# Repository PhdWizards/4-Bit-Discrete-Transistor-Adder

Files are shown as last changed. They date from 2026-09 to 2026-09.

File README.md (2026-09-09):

# 4-Bit Transistor Adder
A fully functional **4-bit binary adder** built using discrete transistor-resistor logic and standard 74HC-series logic ICs.
The project was developed from the initial logic design and transistor-level simulation to a custom two-layer PCB, PCB manufacturing, component assembly, and hardware testing.
The final circuit accepts two 4-bit binary numbers, adds them together, converts the resulting 5-bit value into decimal digits, and displays the result on two 7-segment displays.

## Overview
The main goal of this project was to design and build a physical digital calculator without relying on a microcontroller for the main arithmetic logic.
The core 4-bit adder was developed using **discrete transistor-resistor logic**.
The project includes:
- 4-bit binary addition
- Discrete transistor-based logic
- 5-bit binary result
- Binary-to-BCD conversion
- Two 7-segment displays
- CD4511 BCD-to-7-segment drivers
- Manual binary input using switches
- LED indicators for the binary result
- Custom two-layer PCB
- Complete KiCad schematic
- PCB design and Gerber manufacturing files
- Interactive Bill of Materials
- Falstad and Tinkercad simulations

## Specifications
| Parameter | Value |
|---|---|
| Operation | 4-bit + 4-bit binary addition |
| Input A | 4 bits |
| Input B | 4 bits |
| Result | 5 bits |
| Result range | 0–30 |
| Supply voltage | 5 V |
| Power input | USB-C |
| PCB | 2-layer |
| PCB size | 166.37 × 181.61 mm |
| Main transistor | BC337-25 |
| Transistors | 100 |
| Resistors | 178 |
| 7-segment displays | 2 |
| BCD drivers | 2 × CD4511 |
| Binary input switches | 8 |
| LEDs | 6 |
| Microcontroller | None |

## How It Works

Two 4-bit binary values are entered using eight switches:
```text
A3 A2 A1 A0
B3 B2 B1 B0
```
The values are added together by the transistor-based logic, producing a 5-bit result:
```text
S4 S3 S2 S1 S0
```
The maximum possible result is:
```text
1111₂ + 1111₂ = 11110₂
```
which corresponds to:
```text
30₁₀
```
The 5-bit result is then converted into BCD:
```text
        5-bit Binary Result
                  │
                  ▼
          Binary-to-BCD
           Conversion
                  │
          ┌───────┴───────┐
          ▼               ▼
      Tens BCD         Ones BCD
          │               │
          ▼               ▼
       CD4511           CD4511
          │               │
          ▼               ▼
      7-Segment        7-Segment
       Display           Display
```
For example:
```text
10101₂ = 21₁₀
```
The two displays therefore show:
```text
21
```

## Hardware

### Final Board
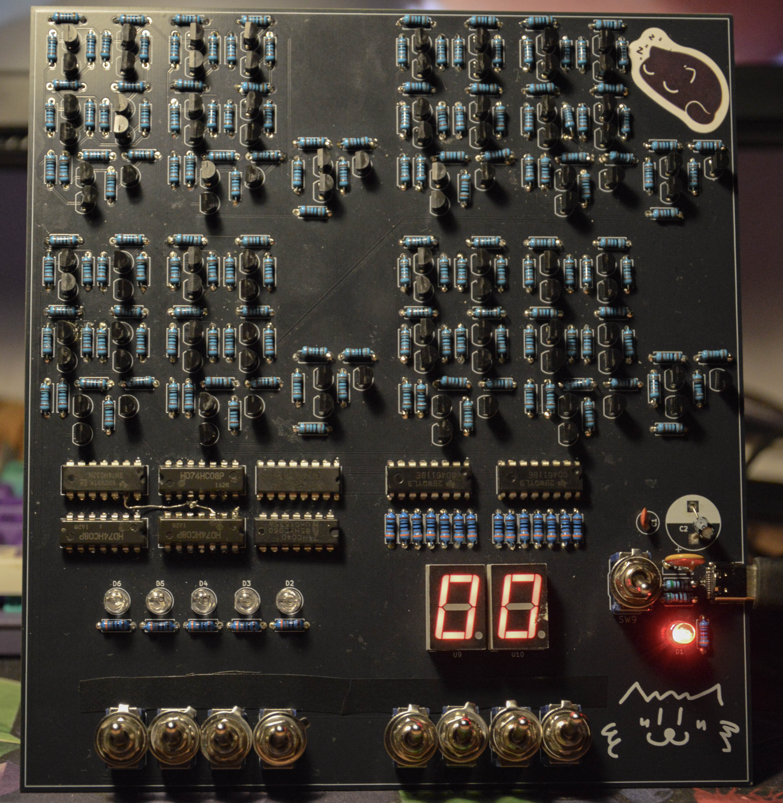
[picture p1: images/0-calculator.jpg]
Final Calculator

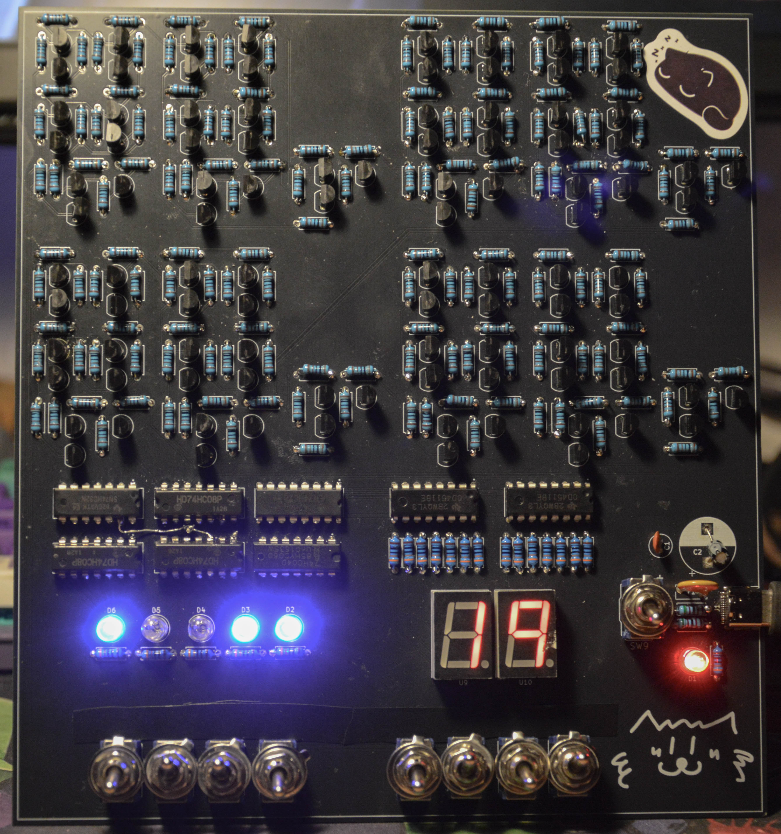
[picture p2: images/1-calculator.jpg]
Working Calculator


## PCB Design

The PCB was designed in **KiCad** as a two-layer board.

### Front Side
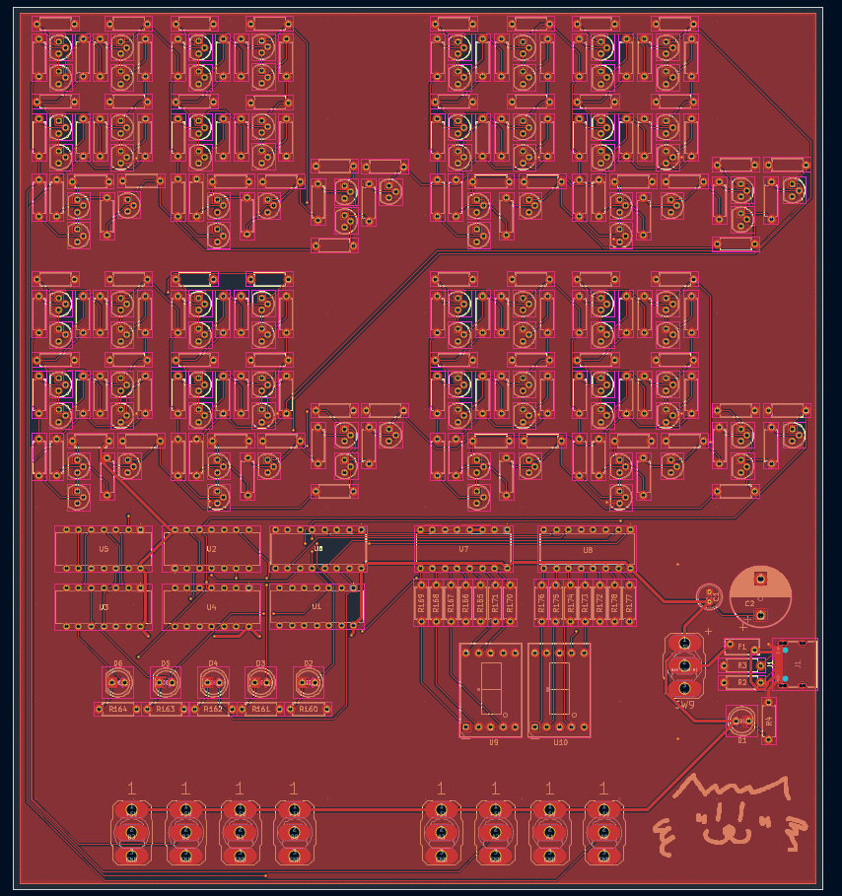
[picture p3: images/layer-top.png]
PCB Front


### Back Side
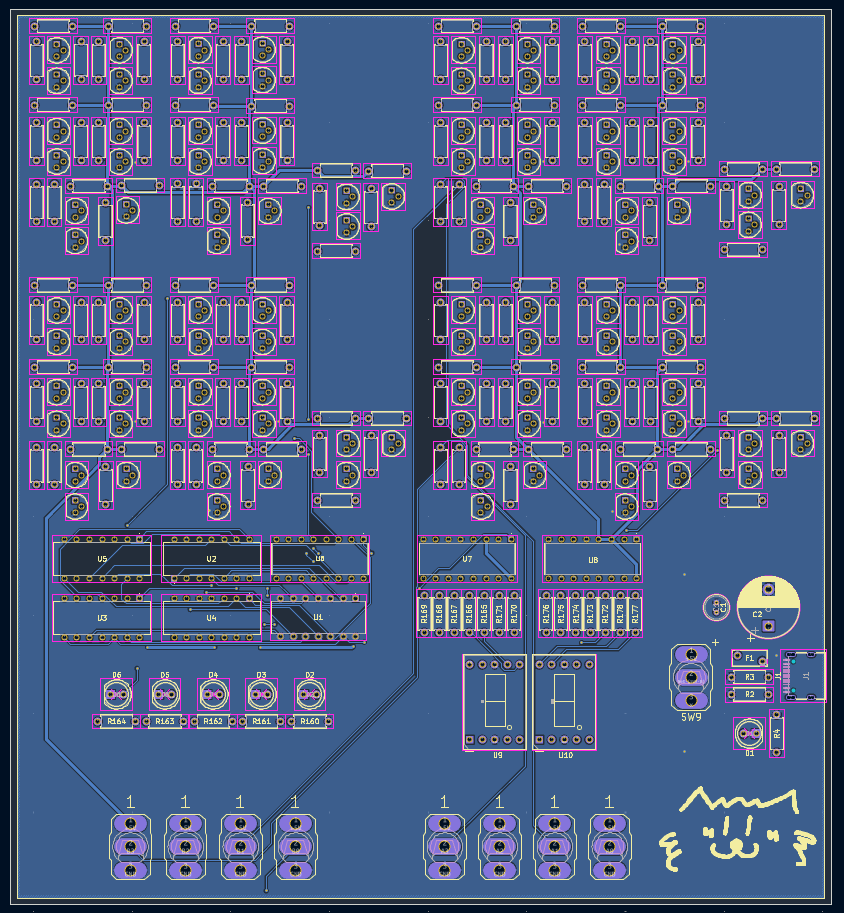
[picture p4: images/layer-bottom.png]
PCB Back


### All Copper Layers
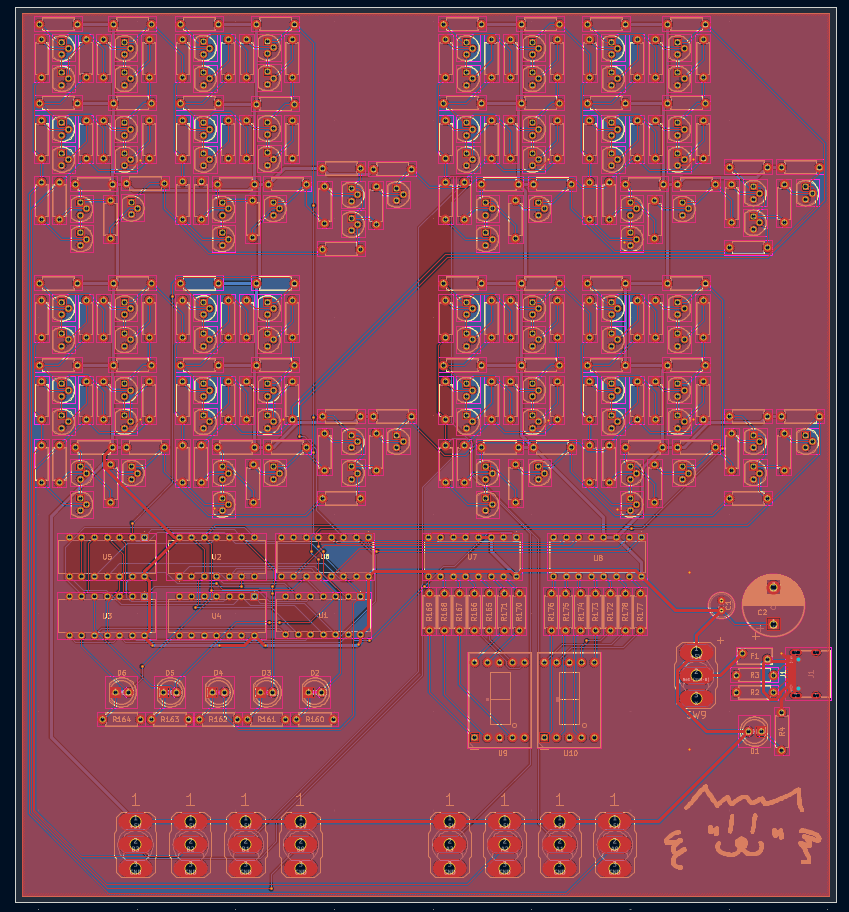
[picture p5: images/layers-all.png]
PCB All Layers


### 3D Model
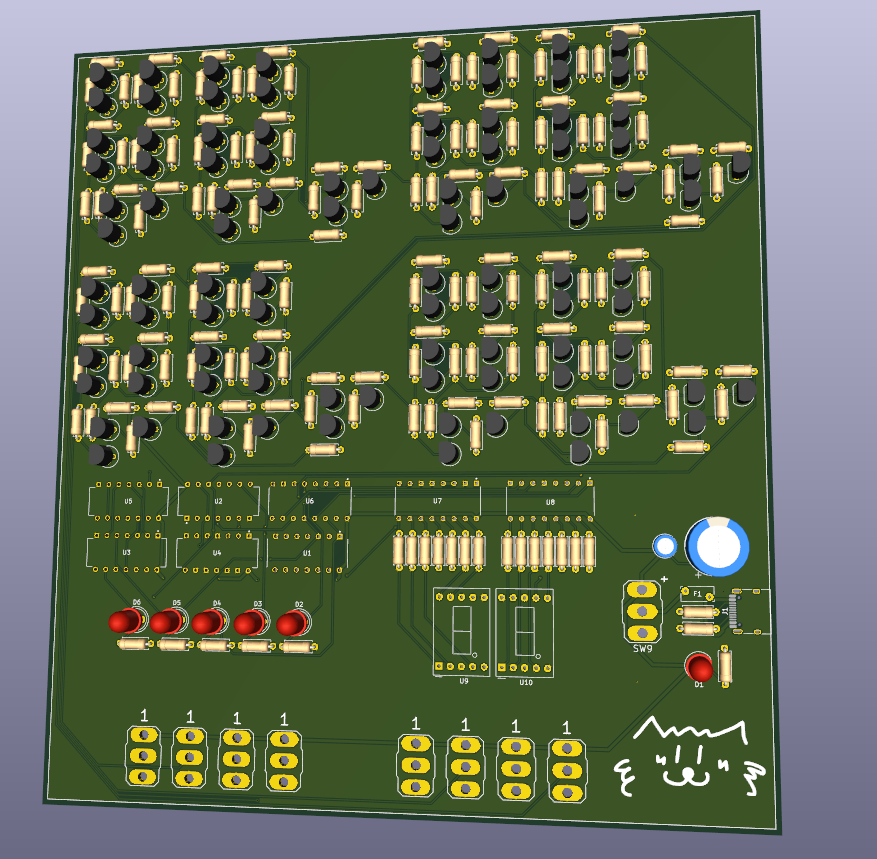
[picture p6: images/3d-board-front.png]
PCB 3D Front

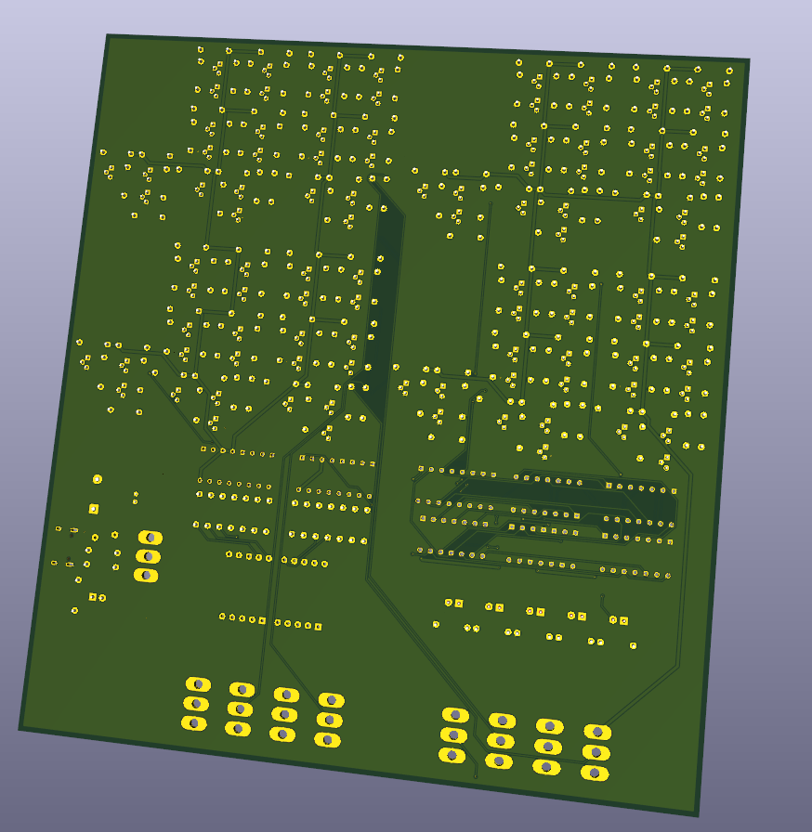
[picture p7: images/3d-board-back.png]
PCB 3D Back


## Schematic
The complete schematic was designed in KiCad and contains the transistor-based adder, logic ICs, BCD conversion, display drivers, inputs, indicators, and power circuitry.
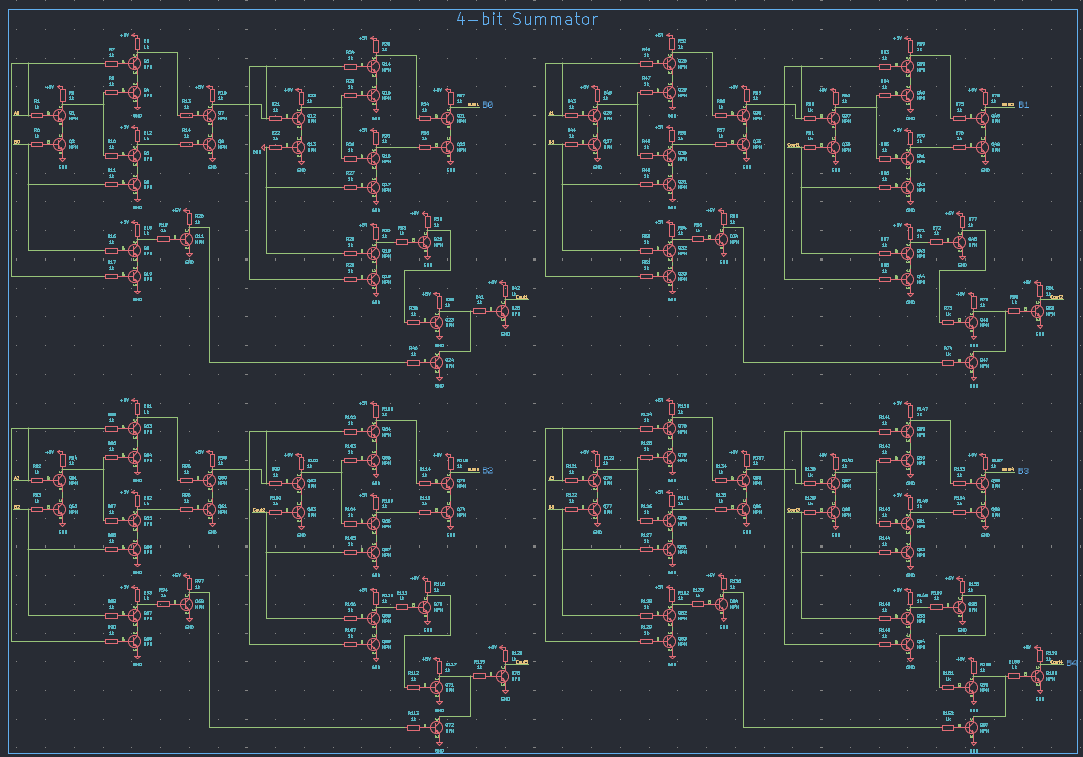
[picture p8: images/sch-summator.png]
Sum-Schematic

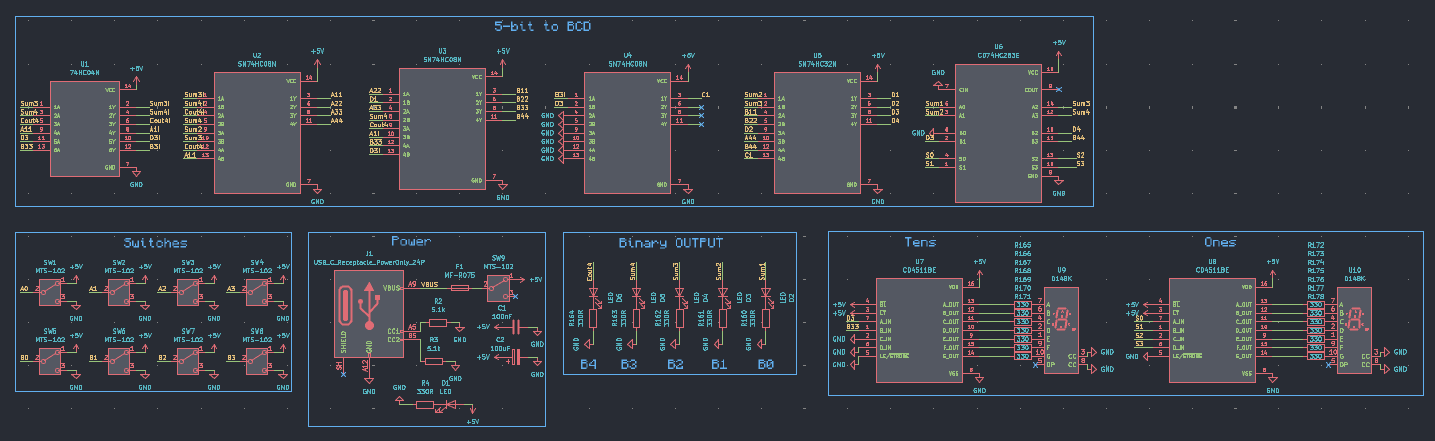
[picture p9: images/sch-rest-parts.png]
Rest-Schematic

A PDF version of the schematic is included in the `schematic` directory.
[**Open Schematic PDF**](schematic/sch.pdf)

## Bill of Materials

An **Interactive BOM** generated from KiCad is included in the repository.
It provides:
- Component references
- Component values
- Footprints
- Quantities
- Front and back PCB views
- Component locations
[**Open Interactive BOM**](bom/calculator-BOM.html)

## Simulation

Simulation was an important part of the development process.
Two different simulation environments were used for different stages of the project.

### Falstad
Falstad was used to learn and develop the transistor-based logic from the ground up.
The 4-bit adder was built step by step, starting from transistor-level digital logic and gradually combining the individual stages into a complete working 4-bit adder.
A downloadable Falstad simulation file is also included in the repository.
[**Open Simulation Documentation**](simulation/README.md)

### Tinkercad
Tinkercad was used to verify the digital logic and binary-to-BCD conversion.
The interactive Tinkercad simulation can be accessed through the simulation documentation.

## Development Process

The project was developed through the following stages:
```text
Concept
   ↓
Logic Design
   ↓
Transistor-Level Development
   ↓
Falstad Simulation
   ↓
Working 4-Bit Adder
   ↓
Tinkercad Simulation
   ↓
KiCad Schematic
   ↓
PCB Layout
   ↓
PCB Manufacturing
   ↓
Component Assembly
   ↓
Hardware Testing
```
The purpose of this workflow was to validate the logic progressively before moving to the final physical implementation.

## Manufacturing Files

The repository contains the files required to reproduce the PCB.
The `pcb` directory includes:
- KiCad PCB files
- Gerber manufacturing files
The schematic directory contains the KiCad schematic and PDF documentation.

## Repository Structure
```text
4-Bit-Transistor-Adder/
│
├── 📁 bom/
│   └── Interactive BOM
│
├── 📁 images/
│   ├── Project photos
│   ├── PCB renders
│   ├── PCB layers
│   ├── Schematic images
│   └── Simulation screenshots
│
├── 📁 pcb/
│   ├── KiCad PCB files
│   └── Gerber files
│
├── 📁 schematic/
│   ├── KiCad schematic
│   └── Schematic PDF
│
├── 📁 simulation/
│   ├── README.md
│   └── Falstad simulation file
│
└── README.md
```

# Tools Used
- **KiCad** — schematic and PCB design
- **Falstad Circuit Simulator** — transistor-level logic development
- **Tinkercad Circuits** — digital logic simulation

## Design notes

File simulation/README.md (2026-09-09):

# Simulation
This folder contains the circuit simulations used during the development of the project.
The simulations were created to study, verify, and test the digital logic before moving to the final schematic and PCB implementation.
Two simulation environments were used during the development process:
- **Falstad Circuit Simulator** — used to learn and develop the transistor-based 4-bit adder from the ground up.
- **Tinkercad Circuits** — used to verify the binary-to-BCD conversion and the final digital logic.

## Overview
The final circuit takes a **5-bit binary input** and converts it into a decimal value displayed on two 7-segment displays.
The binary input is provided using DIP switches. The logic circuit processes the input and produces the corresponding BCD representation for the:
- **Tens digit**
- **Ones digit**
Two **CD4511** BCD-to-7-segment decoder/drivers are used to control the displays.

## Circuit
The simulation contains the following main functional blocks:
```text
          5-bit Binary Input
                 │
                 ▼
        ┌──────────────────┐
        │ Digital Logic    │
        │                  │
        │ 74HC04           │
        │ 74HC08           │
        │ 74HC32           │
        │ 74HC283          │
        └────────┬─────────┘
                 │
                 ▼
          BCD Conversion
                 │
          ┌──────┴──────┐
          ▼             ▼
       Tens BCD      Ones BCD
          │             │
          ▼             ▼
      CD4511          CD4511
          │             │
          ▼             ▼
     7-Segment       7-Segment
      Display         Display
```

## Components Used

### Logic ICs
| Component | Function |
|---|---|
| 74HC04 | NOT gates |
| 74HC08 | AND gates |
| 74HC32 | OR gates |
| 74HC283 | 4-bit binary adder |
| CD4511 | BCD-to-7-segment decoder/driver |

### Other Components
- 2 × 7-segment displays
- DIP switches for binary input
- Current-limiting resistors
- 5 V power supply

# Falstad Simulation
Falstad was the first simulation environment used during the development of the project.
Instead of starting with a complete circuit, the 4-bit adder was developed **from the ground up** using discrete transistor-resistor logic.
The main purpose of this stage was to understand how digital logic gates can be constructed from individual transistors and how these gates can be combined to perform binary addition.

## Learning and Development Process
The development in Falstad followed several stages:
```text
Transistor Basics
       ↓
Logic Gates
       ↓
Half Adder
       ↓
Full Adder
       ↓
4-Bit Adder
```
The circuit was built step by step while testing the behavior of each stage.
The final result was a **fully working 4-bit binary adder** implemented using discrete transistor logic.

## 4-Bit Adder
The completed Falstad simulation contains four 1-bit addition stages connected together to form a 4-bit binary adder.
Each stage processes:
```text
A
B
Cin
```
and produces:
```text
Sum
Cout
```
The carry output of each stage is passed to the next bit.
```text
        ┌─────────────┐
A0 ────►│             │
B0 ────►│  1-Bit      │───► S0
Cin ───►│  Adder      │
        └──────┬──────┘
               │ Cout
               ▼
        ┌─────────────┐
A1 ────►│             │
B1 ────►│  1-Bit      │───► S1
C1 ────►│  Adder      │
        └──────┬──────┘
               │ Cout
               ▼
              ...
```
The completed 4-bit adder was then used as the basis for the hardware implementation.

## Falstad Simulation
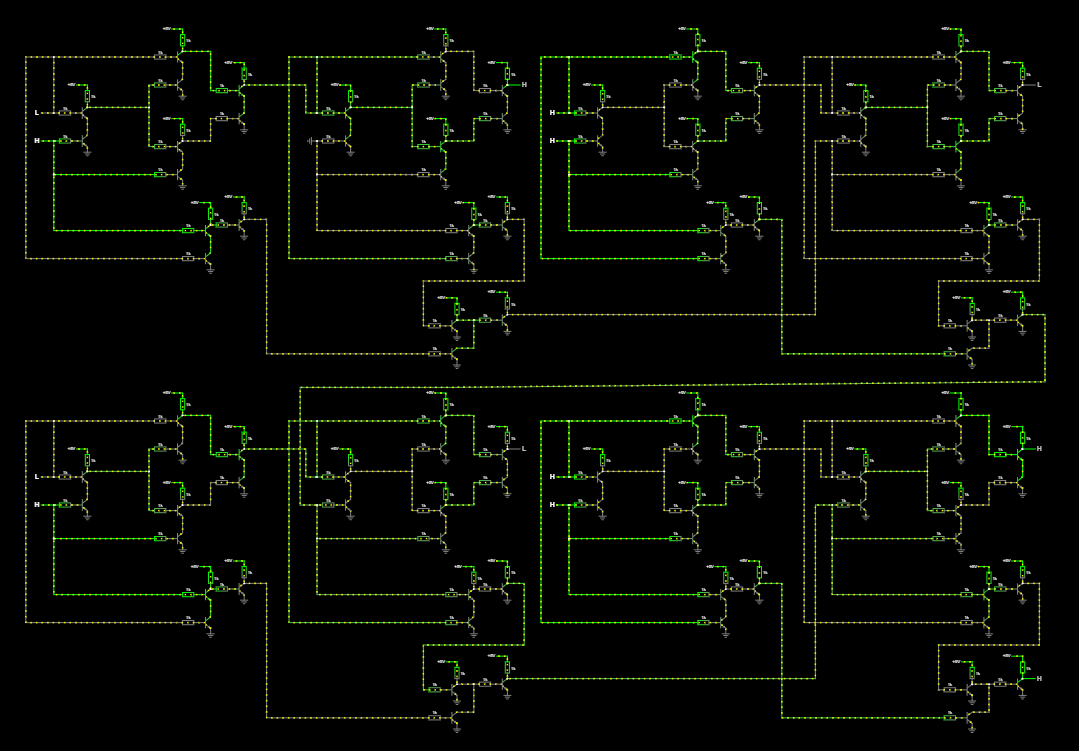
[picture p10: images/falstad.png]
Falstad 4-Bit Adder


### Simulation File
[**Download the Falstad Simulation File**](Summator4bit.txt)
After downloading the file, open it in Falstad to view the complete circuit and inspect how the transistor-based logic works.

# Tinkercad Simulation
The Tinkercad simulation was created to verify the digital logic and the binary-to-BCD conversion before moving to the final schematic and PCB implementation.
The simulation uses standard logic ICs to process the binary input and generate the corresponding BCD output.

## Input
The input is selected using five DIP switches:
```text
B4 B3 B2 B1 B0
```
Each switch represents one bit of the binary input.
The 5-bit input can represent values from:
```text
00000₂ = 0₁₀
```
to:
```text
11111₂ = 31₁₀
```
For example:
```text
Input: 10101₂
```
represents:
```text
21₁₀
```

## Output
The resulting binary value is converted into BCD and split into two decimal digits:
```text
          5-bit Binary
                │
                ▼
        ┌───────────────┐
        │ BCD Conversion│
        └───────┬───────┘
                │
       ┌────────┴────────┐
       ▼                 ▼
   Tens BCD           Ones BCD
       │                 │
       ▼                 ▼
    CD4511             CD4511
       │                 │
       ▼                 ▼
  7-Segment          7-Segment
    Display            Display
```
For example:
```text
Binary: 10101₂

Decimal: 21₁₀

Tens BCD:
0010

Ones BCD:
0001
```
The two 7-segment displays therefore show:
```text
21
```

## Simulation Screenshot
The following image shows the complete simulated circuit in Tinkercad:
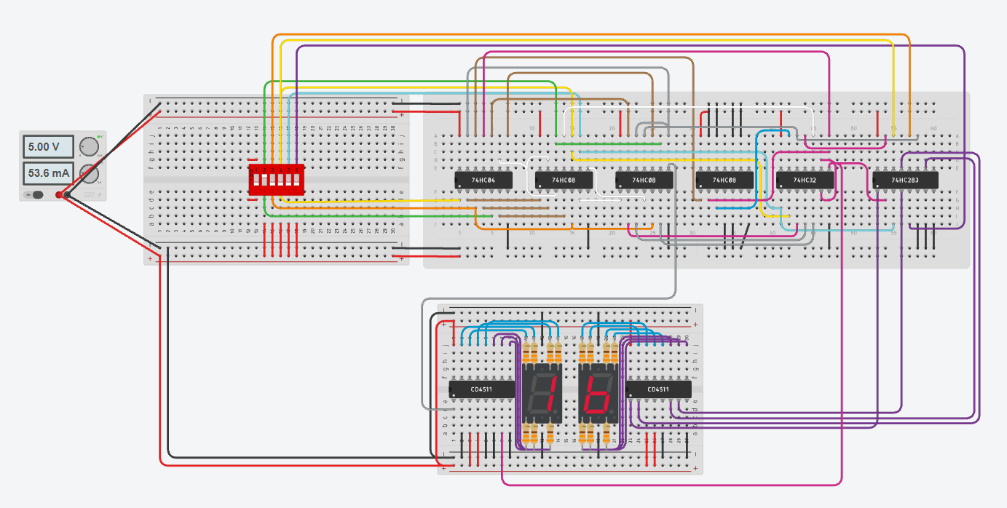
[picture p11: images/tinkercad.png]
Tinkercad Simulation


## Interactive Simulation
The complete interactive simulation is available on Tinkercad:
[**Open Tinkercad Simulation**](https://www.tinkercad.com/things/4N6F5v3ThxK-5-bit-to-bcd-double-dabble)
The simulation can be used to change the binary input and observe the corresponding decimal output on the two 7-segment displays.

# Verification
The simulations were used to verify different parts of the project before moving to the physical implementation.

### Falstad
The Falstad simulation was used to:
- Learn transistor-based digital logic
- Build and test logic gates
- Develop a 1-bit adder
- Combine multiple stages into a 4-bit adder
- Verify carry propagation
- Develop the core transistor-based adder logic

### Tinkercad
The Tinkercad simulation was used to:
- Verify the 5-bit binary input
- Test the digital logic
- Verify binary-to-BCD conversion
- Test the tens digit generation
- Test the ones digit generation
- Verify CD4511 decoder operation
- Verify the 7-segment display output
Different input combinations were tested to ensure that the displayed decimal value matched the expected result.

# Development Process
The simulations were part of the overall hardware development process:
```text
Logic Design
     ↓
Falstad
     ↓
Transistor-Based 4-Bit Adder
     ↓
Tinkercad
     ↓
Binary-to-BCD Logic
     ↓
KiCad Schematic
     ↓
PCB Design
     ↓
PCB Manufacturing
     ↓
Component Assembly
     ↓
Hardware Testing
```
The simulation stage made it possible to develop and verify the logic before committing to the final PCB implementation.

# Related Project Files
The project repository contains the complete design files, including:
```text
📁 bom/
📁 images/
📁 pcb/
📁 schematic/
📁 simulation/
```
The `images` folder contains screenshots and photographs from the development process.
The `simulation` folder contains this documentation.
---

[**Back to Main README**](../README.md)

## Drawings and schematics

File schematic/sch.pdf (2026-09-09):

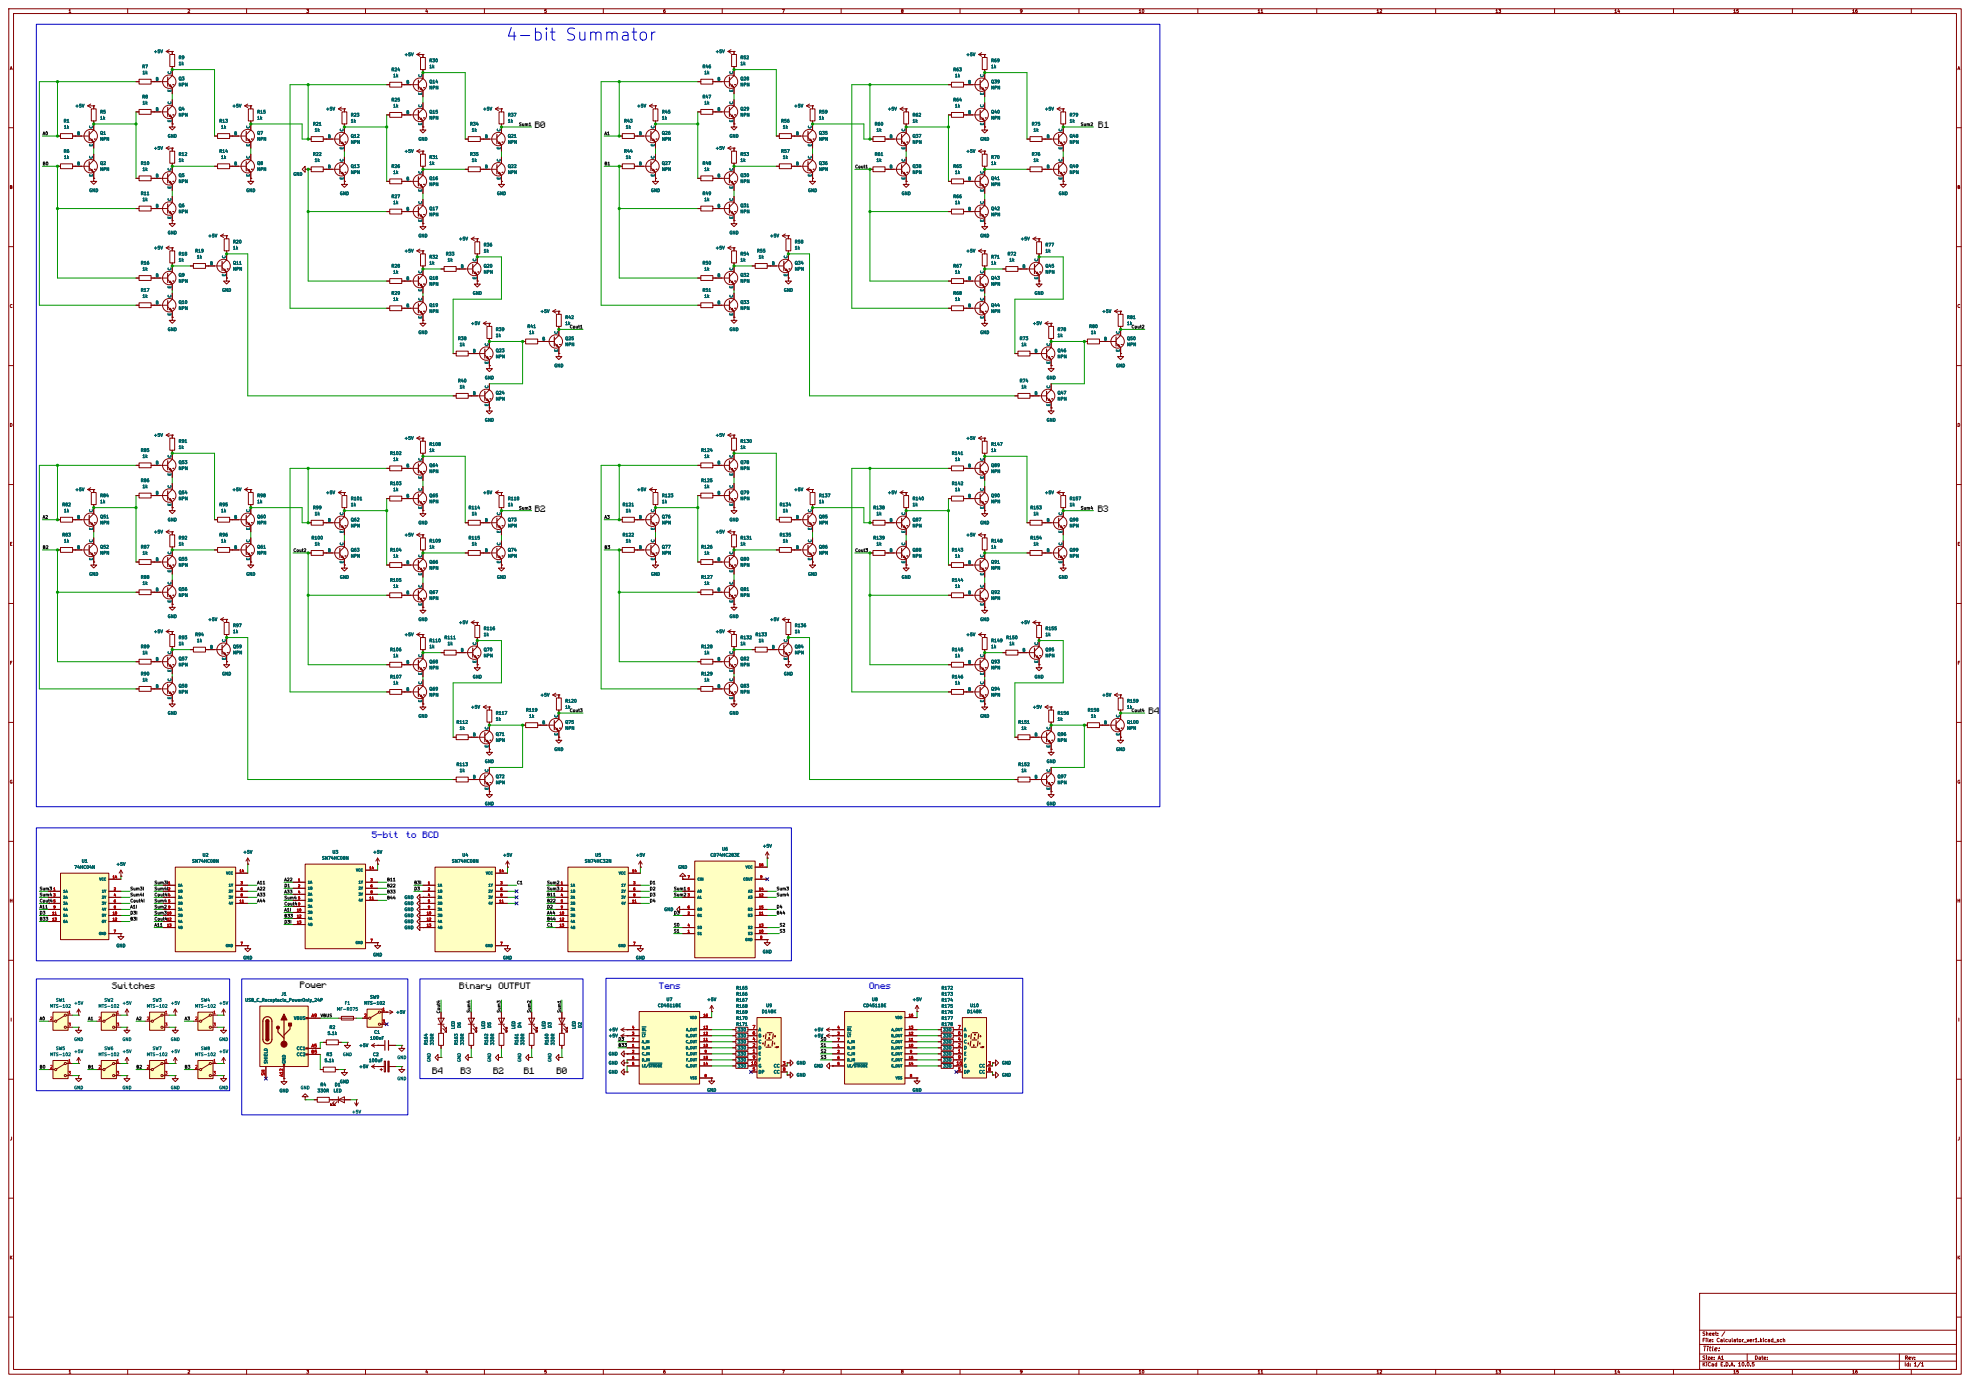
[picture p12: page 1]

Size: A1 | Rev:
KiCad E.D.A. 10.0.5 | Id: 1/1

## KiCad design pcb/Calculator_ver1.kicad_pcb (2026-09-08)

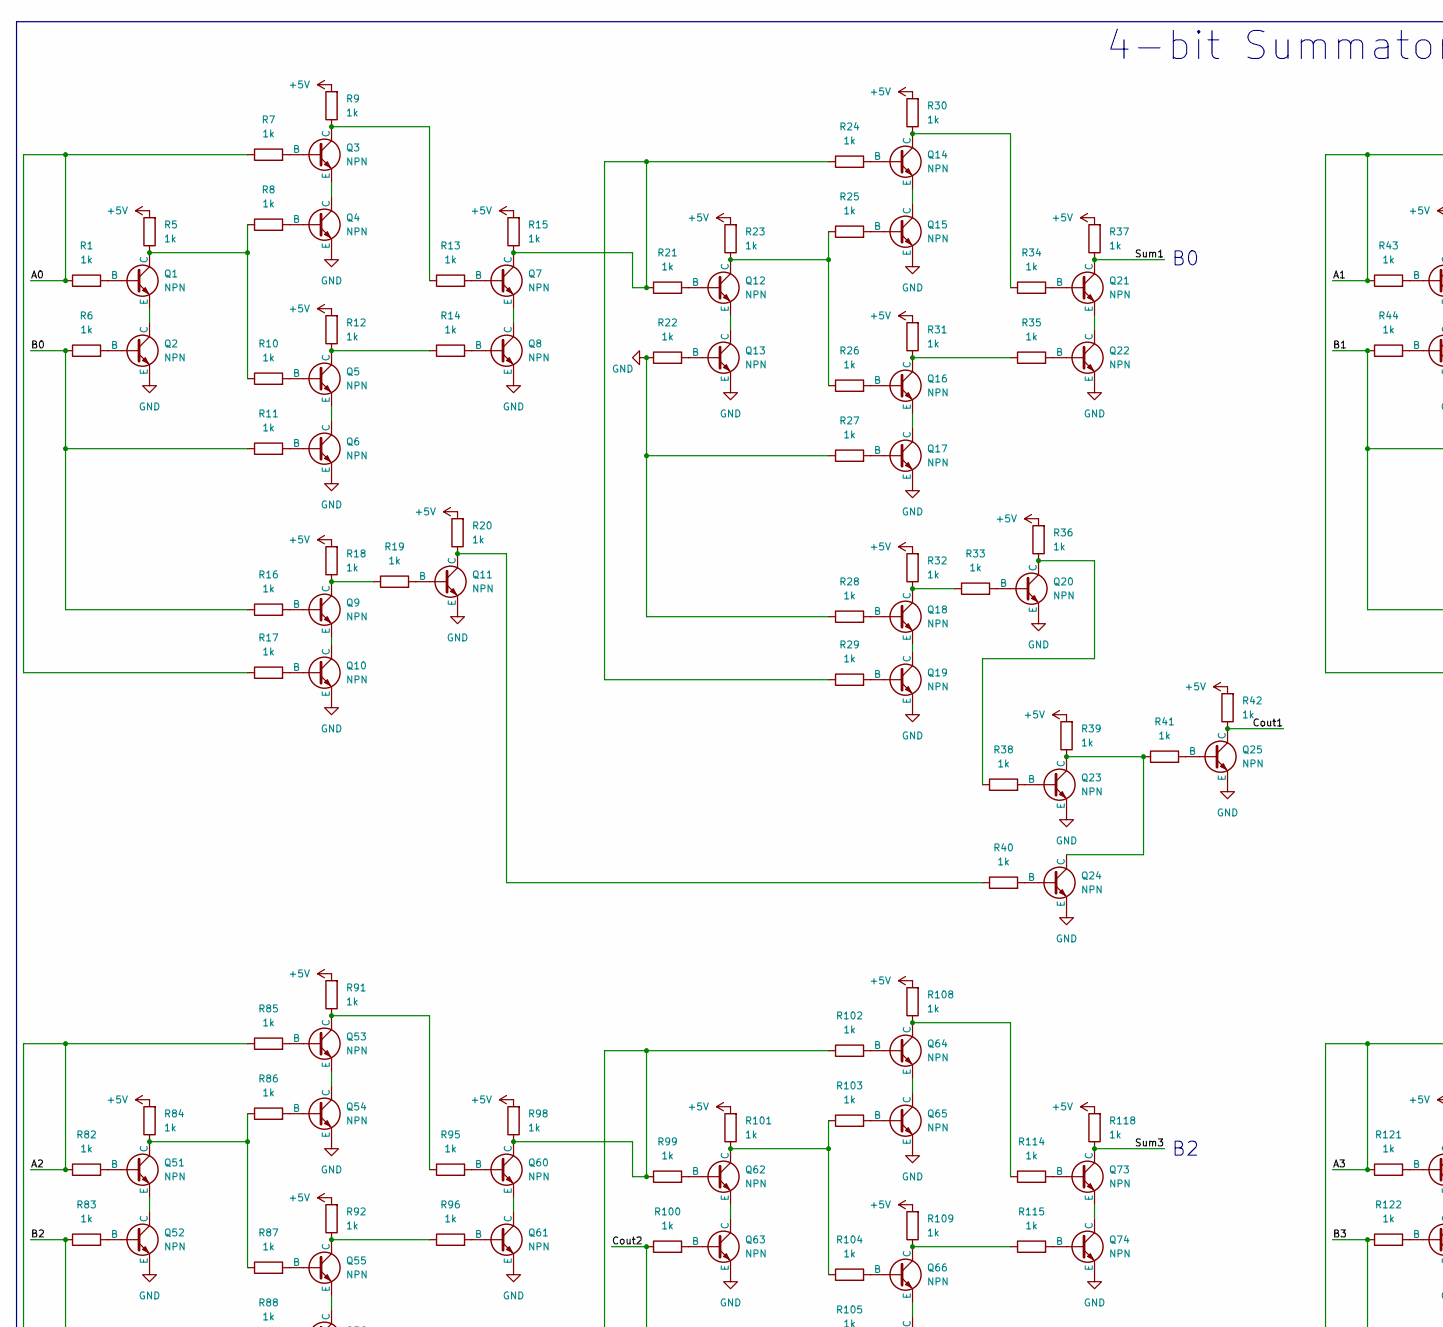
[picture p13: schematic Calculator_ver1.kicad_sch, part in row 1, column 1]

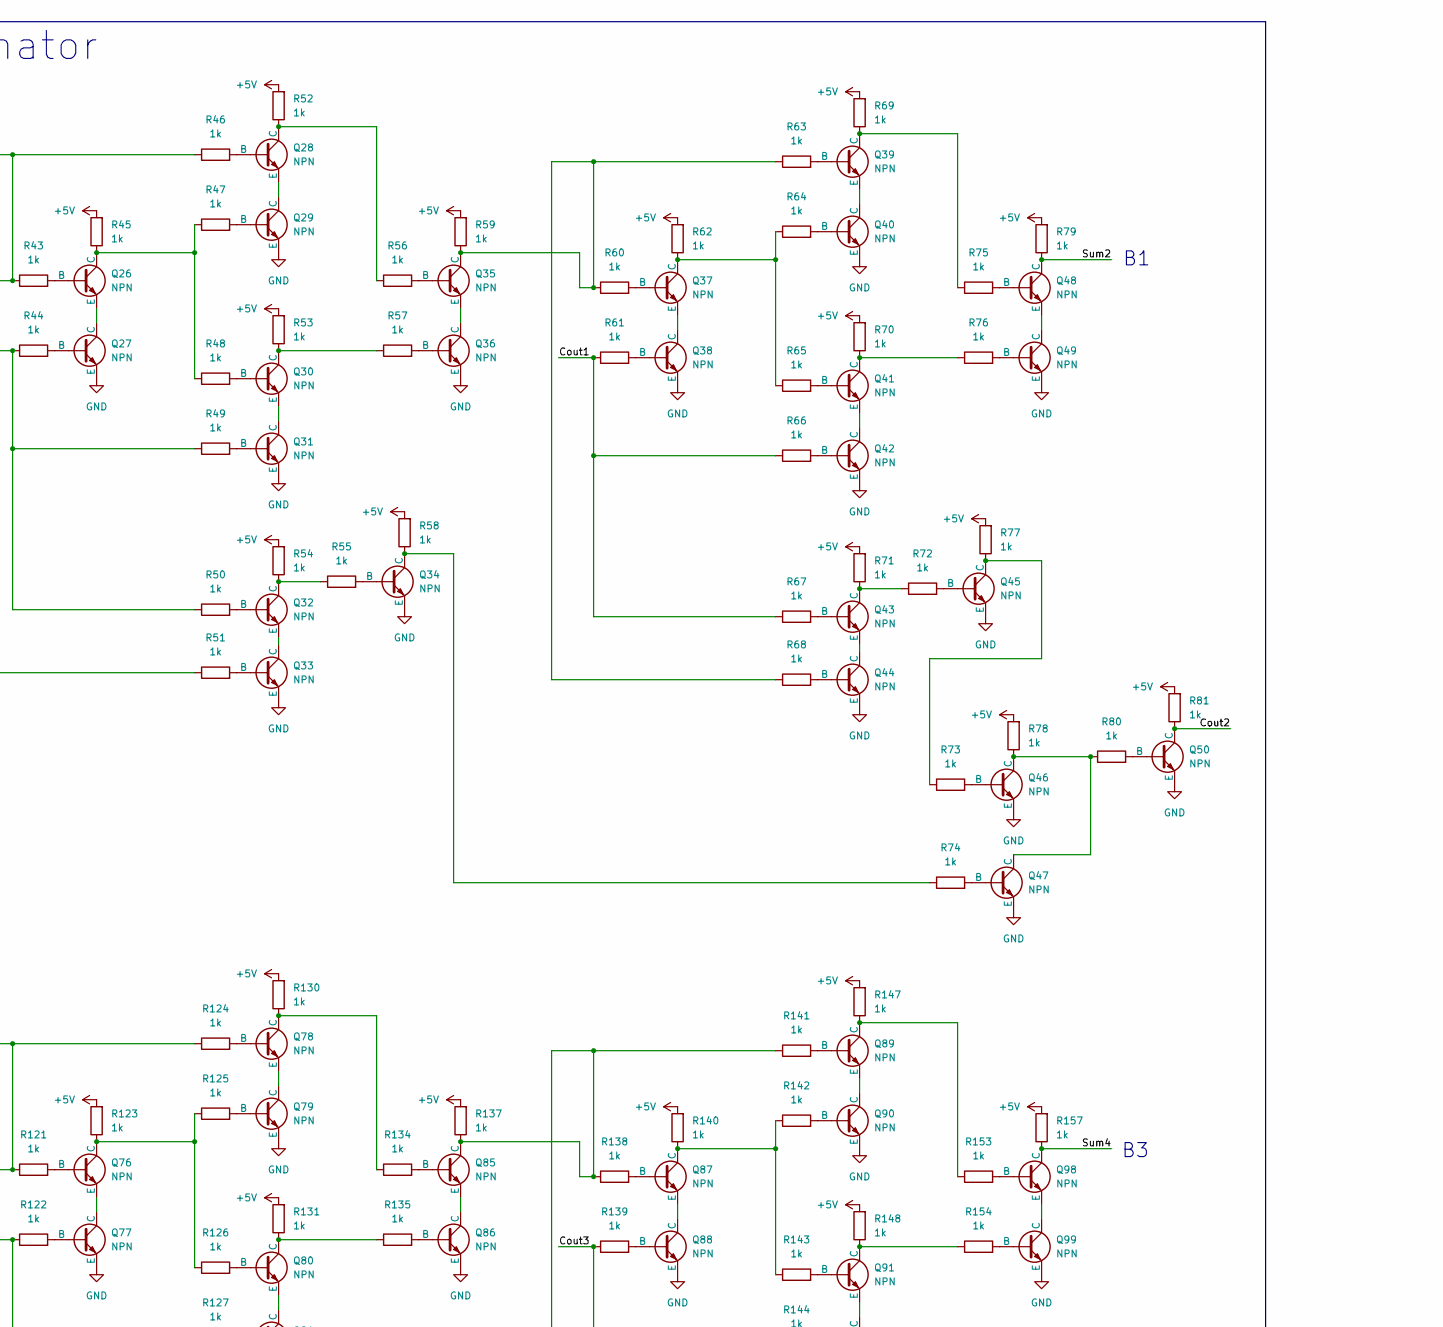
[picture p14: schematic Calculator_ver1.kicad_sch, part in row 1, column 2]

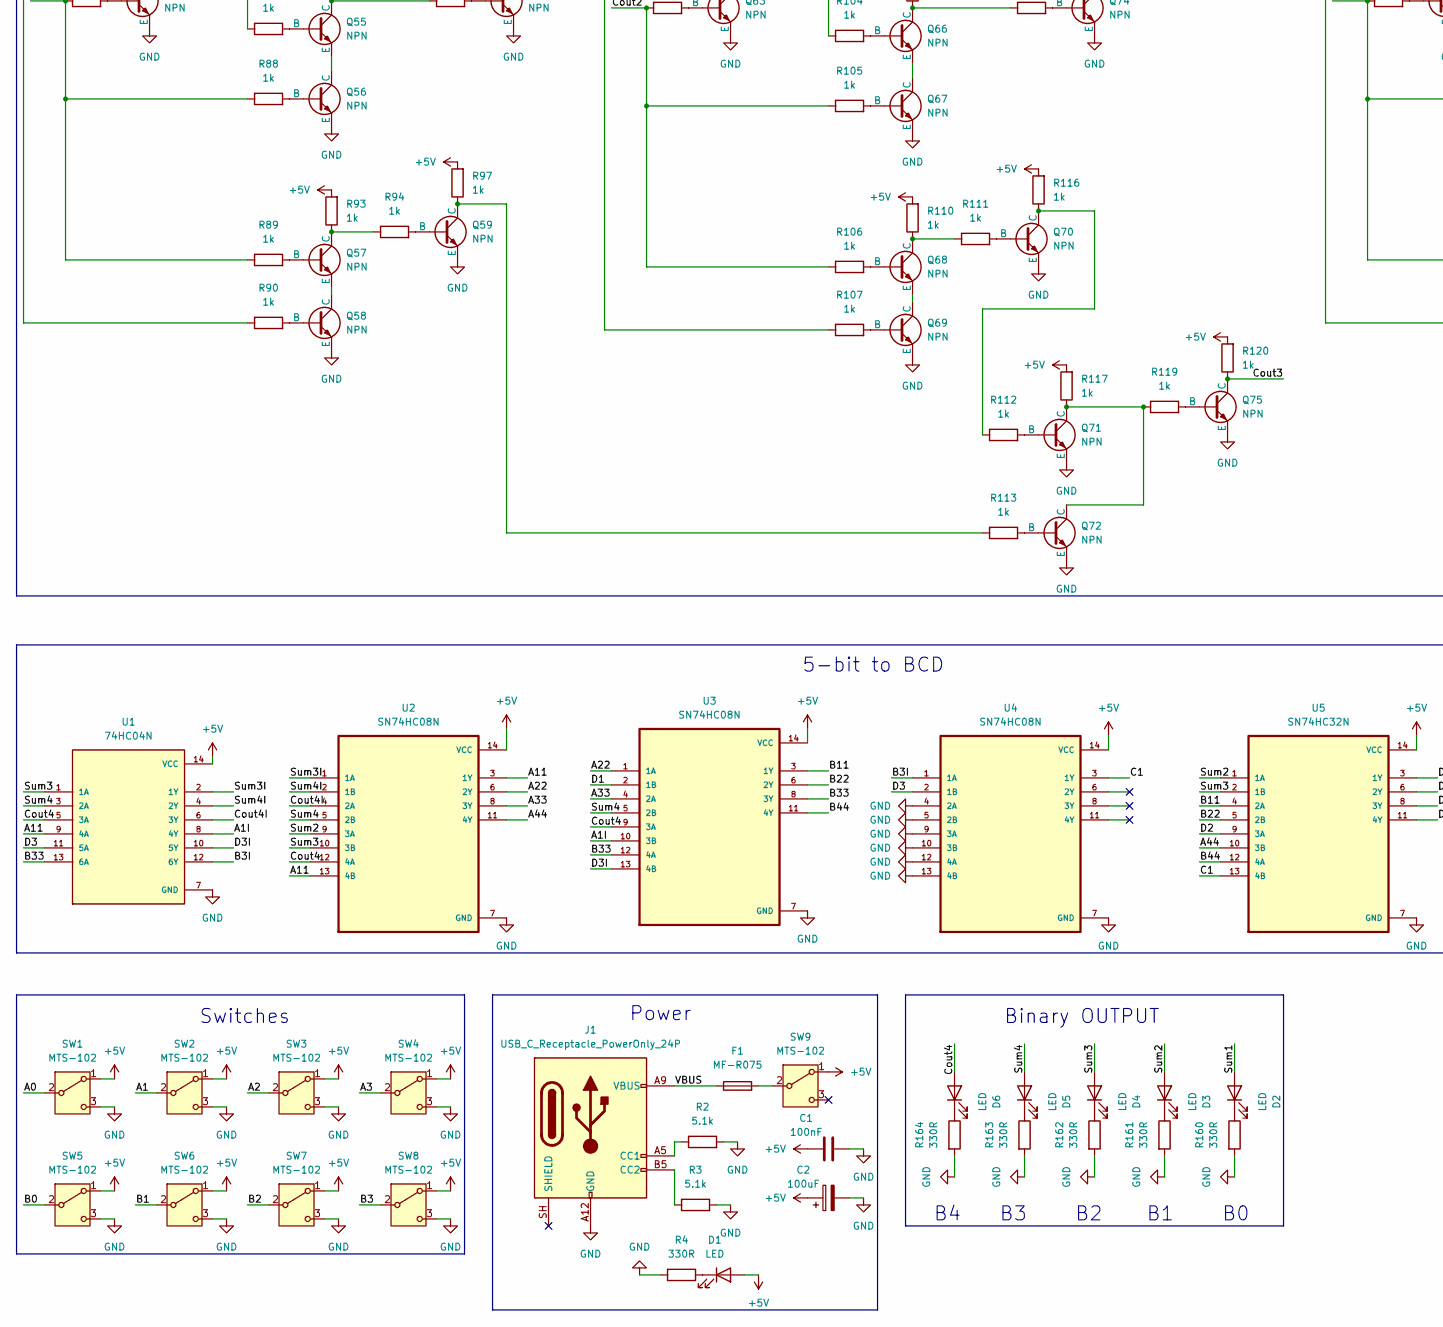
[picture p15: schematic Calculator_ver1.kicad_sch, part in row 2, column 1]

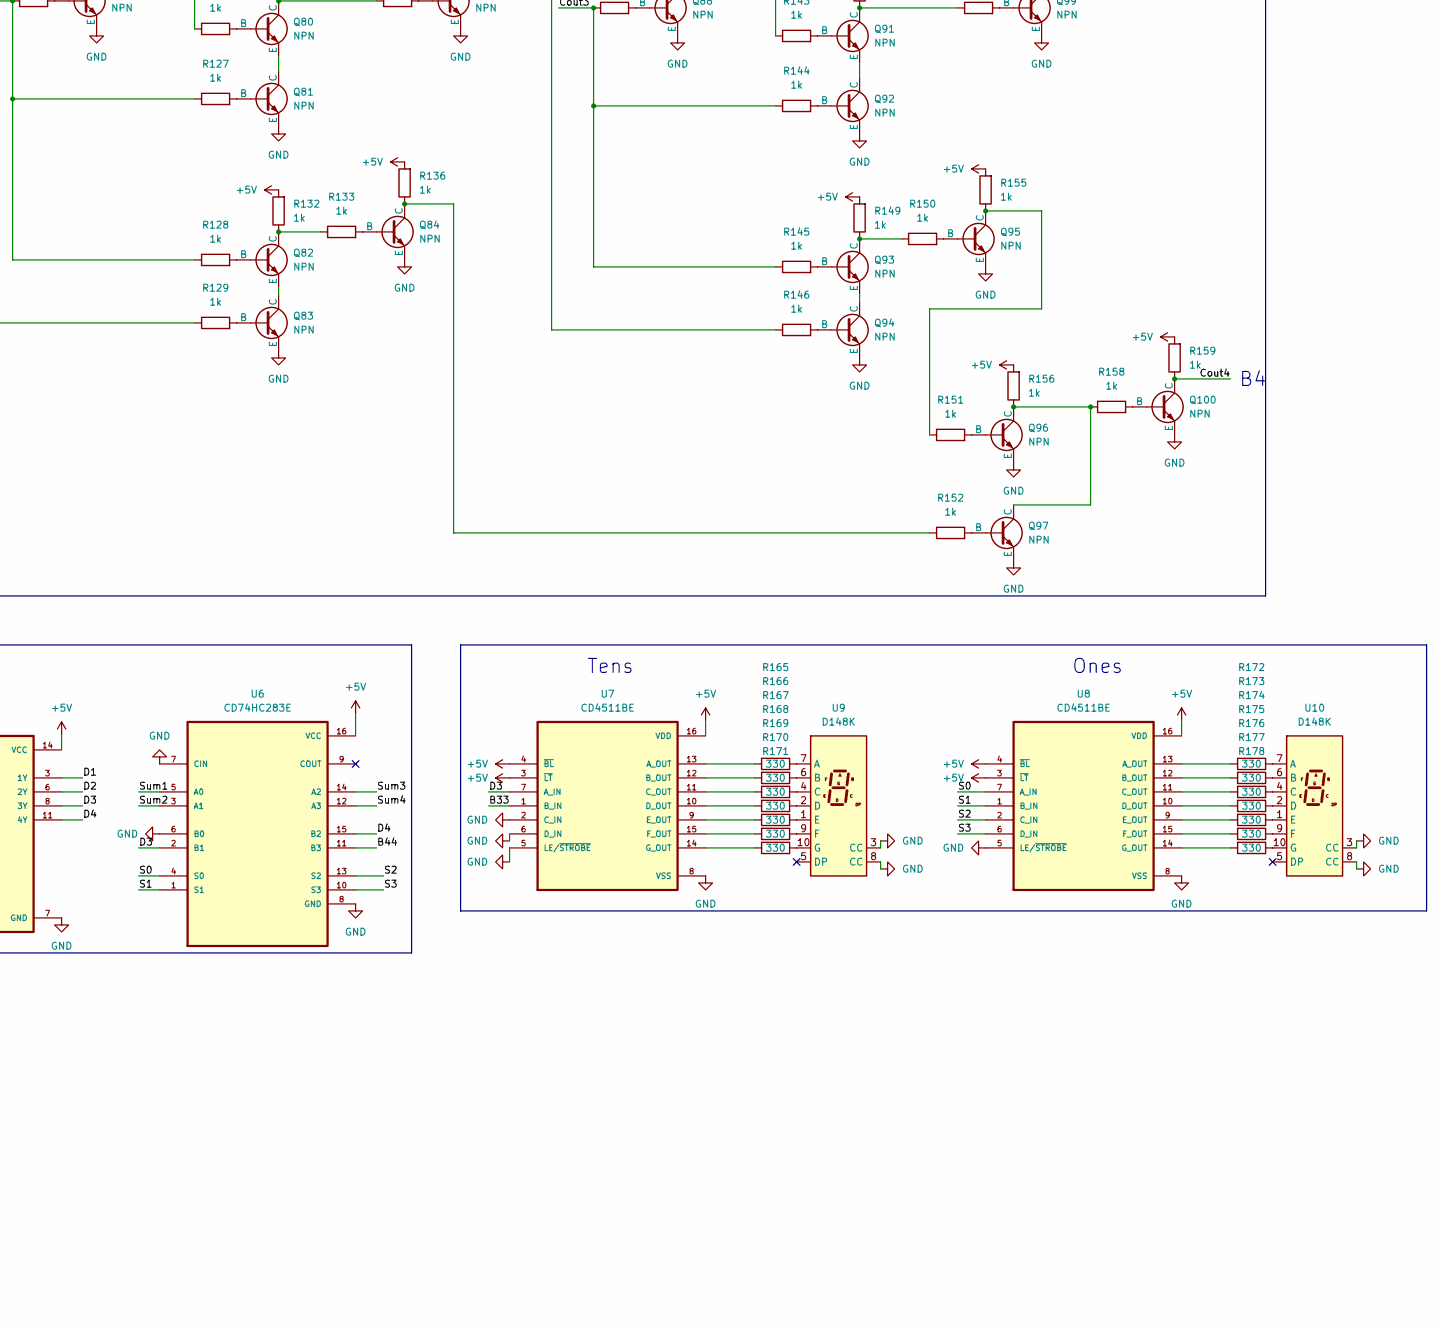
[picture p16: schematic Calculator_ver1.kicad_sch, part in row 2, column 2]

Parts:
C1: 100nF; C_Radial_D5.0mm_H5.0mm_P2.00mm
C2: 100uF; CP_Radial_D12.5mm_P7.50mm
D1, D2, D3, D4, D5, D6: LED; LED_D5.0mm
F1: MF-R075; Fuse_Bourns_MF-RHT070
J1: USB_C_Receptacle_PowerOnly_24P; USB_C_Receptacle_HRO_TYPE-C-31-M-12
Q1, Q2, Q3, Q4, Q5, Q6, Q7, Q8, Q9, Q10, Q11, Q12, Q13, Q14, Q15, Q16, Q17, Q18, Q19, Q20, Q21, Q22, Q23, Q24, Q25, Q26, Q27, Q28, Q29, Q30, Q31, Q32, Q33, Q34, Q35, Q36, Q37, Q38, Q39, Q40, Q41, Q42, Q43, Q44, Q45, Q46, Q47, Q48, Q49, Q50, Q51, Q52, Q53, Q54, Q55, Q56, Q57, Q58, Q59, Q60, Q61, Q62, Q63, Q64, Q65, Q66, Q67, Q68, Q69, Q70, Q71, Q72, Q73, Q74, Q75, Q76, Q77, Q78, Q79, Q80, Q81, Q82, Q83, Q84, Q85, Q86, Q87, Q88, Q89, Q90, Q91, Q92, Q93, Q94, Q95, Q96, Q97, Q98, Q99, Q100: NPN; TO-92
R1, R5, R6, R7, R8, R9, R10, R11, R12, R13, R14, R15, R16, R17, R18, R19, R20, R21, R22, R23, R24, R25, R26, R27, R28, R29, R30, R31, R32, R33, R34, R35, R36, R37, R38, R39, R40, R41, R42, R43, R44, R45, R46, R47, R48, R49, R50, R51, R52, R53, R54, R55, R56, R57, R58, R59, R60, R61, R62, R63, R64, R65, R66, R67, R68, R69, R70, R71, R72, R73, R74, R75, R76, R77, R78, R79, R80, R81, R82, R83, R84, R85, R86, R87, R88, R89, R90, R91, R92, R93, R94, R95, R96, R97, R98, R99, R100, R101, R102, R103, R104, R105, R106, R107, R108, R109, R110, R111, R112, R113, R114, R115, R116, R117, R118, R119, R120, R121, R122, R123, R124, R125, R126, R127, R128, R129, R130, R131, R132, R133, R134, R135, R136, R137, R138, R139, R140, R141, R142, R143, R144, R145, R146, R147, R148, R149, R150, R151, R152, R153, R154, R155, R156, R157, R158, R159: 1k; R_Axial_DIN0207_L6.3mm_D2.5mm_P7.62mm_Horizontal
R2, R3: 5.1k; R_Axial_DIN0207_L6.3mm_D2.5mm_P7.62mm_Horizontal
R4, R160, R161, R162, R163, R164: 330R; R_Axial_DIN0207_L6.3mm_D2.5mm_P7.62mm_Horizontal
R165, R166, R167, R168, R169, R170, R171, R172, R173, R174, R175, R176, R177, R178: 330; R_Axial_DIN0207_L6.3mm_D2.5mm_P7.62mm_Horizontal
SW1, SW2, SW3, SW4, SW5, SW6, SW7, SW8, SW9: MTS-102
U1: 74HC04N; DIP764W47P254L1920H431Q14
U2, U3, U4: SN74HC08N; DIP794W45P254L1969H508Q14
U5: SN74HC32N; DIP794W45P254L1969H508Q14
U6: CD74HC283E; DIP794W45P254L1969H508Q16
U7, U8: CD4511BE; DIP794W45P254L1969H508Q16
U9, U10: D148K; D1X8K

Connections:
+5V: C1.1, C2.1, D1.2 (A), R5.2, R9.2, R12.2, R15.2, R18.2, R20.2, R23.2, R30.2, R31.2, R32.2, R36.2, R37.2, R39.2, R42.2, R45.2, R52.2, R53.2, R54.2, R58.2, R59.2, R62.2, R69.2, R70.2, R71.2, R77.2, R78.2, R79.2, R81.2, R84.2, R91.2, R92.2, R93.2, R97.2, R98.2, R101.2, R108.2, R109.2, R110.2, R116.2, R117.2, R118.2, R120.2, R123.2, R130.2, R131.2, R132.2, R136.2, R137.2, R140.2, R147.2, R148.2, R149.2, R155.2, R156.2, R157.2, R159.2, SW1.1 (A), SW2.1 (A), SW3.1 (A), SW4.1 (A), SW5.1 (A), SW6.1 (A), SW7.1 (A), SW8.1 (A), SW9.1 (A), U1.14 (VCC), U2.14 (VCC), U3.14 (VCC), U4.14 (VCC), U5.14 (VCC), U6.16 (VCC), U7.3 (~LT), U7.4 (~BL), U7.16 (VDD), U8.3 (~LT), U8.4 (~BL), U8.16 (VDD)
/A0: R1.1, R7.1, R17.1, SW1.2 (B)
/A1: R43.1, R46.1, R51.1, SW2.2 (B)
/A1I: U1.8 (4Y), U3.10 (3B)
/A2: R82.1, R85.1, R90.1, SW3.2 (B)
/A3: R121.1, R124.1, R129.1, SW4.2 (B)
/A11: U1.9 (4A), U2.3 (1Y), U2.13 (4B)
/A22: U2.6 (2Y), U3.1 (1A)
/A33: U2.8 (3Y), U3.4 (2A)
/A44: U2.11 (4Y), U5.10 (3B)
/B0: R6.1, R11.1, R16.1, SW5.2 (B)
/B1: R44.1, R49.1, R50.1, SW6.2 (B)
/B2: R83.1, R88.1, R89.1, SW7.2 (B)
/B3: R122.1, R127.1, R128.1, SW8.2 (B)
/B3I: U1.12 (6Y), U4.1 (1A)
/B11: U3.3 (1Y), U5.4 (2A)
/B22: U3.6 (2Y), U5.5 (2B)
/B33: U1.13 (6A), U3.8 (3Y), U3.12 (4A), U7.1 (B_IN)
/B44: U3.11 (4Y), U5.12 (4A), U6.11 (B3)
/C1: U4.3 (1Y), U5.13 (4B)
/Cout1: Q25.1 (C), R42.1, R61.1, R66.1, R67.1
/Cout2: Q50.1 (C), R81.1, R100.1, R105.1, R106.1
/Cout3: Q75.1 (C), R120.1, R139.1, R144.1, R145.1
/Cout4: D6.2 (A), Q100.1 (C), R159.1, U1.5 (3A), U2.12 (4A), U3.9 (3A)
/Cout4I: U1.6 (3Y), U2.4 (2A)
/D1: U3.2 (1B), U5.3 (1Y)
/D2: U5.6 (2Y), U5.9 (3A)
/D3: U1.11 (5A), U4.2 (1B), U5.8 (3Y), U6.2 (B1), U7.7 (A_IN)
/D3I: U1.10 (5Y), U3.13 (4B)
/D4: U5.11 (4Y), U6.15 (B2)
/S0: U6.4 (S0), U8.7 (A_IN)
/S1: U6.1 (S1), U8.1 (B_IN)
/S2: U6.13 (S2), U8.2 (C_IN)
/S3: U6.10 (S3), U8.6 (D_IN)
/Sum1: D2.2 (A), Q21.1 (C), R37.1, U6.5 (A0)
/Sum2: D3.2 (A), Q48.1 (C), R79.1, U2.9 (3A), U5.1 (1A), U6.3 (A1)
/Sum3: D4.2 (A), Q73.1 (C), R118.1, U1.1 (1A), U2.10 (3B), U5.2 (1B), U6.14 (A2)
/Sum3I: U1.2 (1Y), U2.1 (1A)
/Sum4: D5.2 (A), Q98.1 (C), R157.1, U1.3 (2A), U2.5 (2B), U3.5 (2B), U6.12 (A3)
/Sum4I: U1.4 (2Y), U2.2 (1B)
/VBUS: F1.1, J1.A4 (VBUS), J1.A9 (VBUS), J1.B4 (VBUS), J1.B9 (VBUS)
GND: C1.2, C2.2, J1.A1 (GND), J1.A12 (GND), J1.B1 (GND), J1.B12 (GND), Q2.3 (E), Q4.3 (E), Q6.3 (E), Q8.3 (E), Q10.3 (E), Q11.3 (E), Q13.3 (E), Q15.3 (E), Q17.3 (E), Q19.3 (E), Q20.3 (E), Q22.3 (E), Q23.3 (E), Q24.3 (E), Q25.3 (E), Q27.3 (E), Q29.3 (E), Q31.3 (E), Q33.3 (E), Q34.3 (E), Q36.3 (E), Q38.3 (E), Q40.3 (E), Q42.3 (E), Q44.3 (E), Q45.3 (E), Q46.3 (E), Q47.3 (E), Q49.3 (E), Q50.3 (E), Q52.3 (E), Q54.3 (E), Q56.3 (E), Q58.3 (E), Q59.3 (E), Q61.3 (E), Q63.3 (E), Q65.3 (E), Q67.3 (E), Q69.3 (E), Q70.3 (E), Q71.3 (E), Q72.3 (E), Q74.3 (E), Q75.3 (E), Q77.3 (E), Q79.3 (E), Q81.3 (E), Q83.3 (E), Q84.3 (E), Q86.3 (E), Q88.3 (E), Q90.3 (E), Q92.3 (E), Q94.3 (E), Q95.3 (E), Q96.3 (E), Q97.3 (E), Q99.3 (E), Q100.3 (E), R2.2, R3.2, R4.2, R22.1, R27.1, R28.1, R160.2, R161.2, R162.2, R163.2, R164.2, SW1.3 (C), SW2.3 (C), SW3.3 (C), SW4.3 (C), SW5.3 (C), SW6.3 (C), SW7.3 (C), SW8.3 (C), U1.7 (GND), U2.7 (GND), U3.7 (GND), U4.4 (2A), U4.5 (2B), U4.7 (GND), U4.9 (3A), U4.10 (3B), U4.12 (4A), U4.13 (4B), U5.7 (GND), U6.6 (B0), U6.7 (CIN), U6.8 (GND), U7.2 (C_IN), U7.5 (LE/~STROBE), U7.6 (D_IN), U7.8 (VSS), U8.5 (LE/~STROBE), U8.8 (VSS), U9.3 (CC), U9.8 (CC), U10.3 (CC), U10.8 (CC)
unnamed: D1.1 (K), R4.1
unnamed: D2.1 (K), R160.1
unnamed: D3.1 (K), R161.1
unnamed: D4.1 (K), R162.1
unnamed: D5.1 (K), R163.1
unnamed: D6.1 (K), R164.1
unnamed: J1.A5 (CC1), R2.1
unnamed: J1.B5 (CC2), R3.1
unnamed: Q1.2 (B), R1.2
unnamed: Q1.1 (C), R5.1, R8.1, R10.1
unnamed: Q1.3 (E), Q2.1 (C)
unnamed: Q2.2 (B), R6.2
unnamed: Q3.2 (B), R7.2
unnamed: Q3.1 (C), R9.1, R13.1
unnamed: Q3.3 (E), Q4.1 (C)
unnamed: Q4.2 (B), R8.2
unnamed: Q5.2 (B), R10.2
unnamed: Q5.1 (C), R12.1, R14.1
unnamed: Q5.3 (E), Q6.1 (C)
unnamed: Q6.2 (B), R11.2
unnamed: Q7.2 (B), R13.2
unnamed: Q7.1 (C), R15.1, R21.1, R24.1, R29.1
unnamed: Q7.3 (E), Q8.1 (C)
unnamed: Q8.2 (B), R14.2
unnamed: Q9.2 (B), R16.2
unnamed: Q9.1 (C), R18.1, R19.1
unnamed: Q10.2 (B), R17.2
unnamed: Q9.3 (E), Q10.1 (C)
unnamed: Q11.2 (B), R19.2
unnamed: Q11.1 (C), R20.1, R40.1
unnamed: Q12.2 (B), R21.2
unnamed: Q12.1 (C), R23.1, R25.1, R26.1
unnamed: Q12.3 (E), Q13.1 (C)
unnamed: Q13.2 (B), R22.2
unnamed: Q14.2 (B), R24.2
unnamed: Q14.1 (C), R30.1, R34.1
unnamed: Q14.3 (E), Q15.1 (C)
unnamed: Q15.2 (B), R25.2
unnamed: Q16.2 (B), R26.2
unnamed: Q16.1 (C), R31.1, R35.1
unnamed: Q16.3 (E), Q17.1 (C)
unnamed: Q17.2 (B), R27.2
unnamed: Q18.2 (B), R28.2
unnamed: Q18.1 (C), R32.1, R33.1
unnamed: Q18.3 (E), Q19.1 (C)
unnamed: Q19.2 (B), R29.2
unnamed: Q20.2 (B), R33.2
unnamed: Q20.1 (C), R36.1, R38.1
unnamed: Q21.2 (B), R34.2
unnamed: Q21.3 (E), Q22.1 (C)
unnamed: Q22.2 (B), R35.2
unnamed: Q23.2 (B), R38.2
unnamed: Q23.1 (C), Q24.1 (C), R39.1, R41.1
unnamed: Q24.2 (B), R40.2
unnamed: Q25.2 (B), R41.2
unnamed: Q26.2 (B), R43.2
unnamed: Q26.1 (C), R45.1, R47.1, R48.1
unnamed: Q26.3 (E), Q27.1 (C)
unnamed: Q27.2 (B), R44.2
unnamed: Q28.2 (B), R46.2
unnamed: Q28.1 (C), R52.1, R56.1
unnamed: Q28.3 (E), Q29.1 (C)
unnamed: Q29.2 (B), R47.2
unnamed: Q30.2 (B), R48.2
unnamed: Q30.1 (C), R53.1, R57.1
unnamed: Q30.3 (E), Q31.1 (C)
unnamed: Q31.2 (B), R49.2
unnamed: Q32.2 (B), R50.2
unnamed: Q32.1 (C), R54.1, R55.1
unnamed: Q32.3 (E), Q33.1 (C)
unnamed: Q33.2 (B), R51.2
unnamed: Q34.2 (B), R55.2
unnamed: Q34.1 (C), R58.1, R74.1
unnamed: Q35.2 (B), R56.2
unnamed: Q35.1 (C), R59.1, R60.1, R63.1, R68.1
unnamed: Q35.3 (E), Q36.1 (C)
unnamed: Q36.2 (B), R57.2
unnamed: Q37.2 (B), R60.2
unnamed: Q37.1 (C), R62.1, R64.1, R65.1
unnamed: Q37.3 (E), Q38.1 (C)
unnamed: Q38.2 (B), R61.2
unnamed: Q39.2 (B), R63.2
unnamed: Q39.1 (C), R69.1, R75.1
unnamed: Q39.3 (E), Q40.1 (C)
unnamed: Q40.2 (B), R64.2
unnamed: Q41.2 (B), R65.2
unnamed: Q41.1 (C), R70.1, R76.1
unnamed: Q41.3 (E), Q42.1 (C)
unnamed: Q42.2 (B), R66.2
unnamed: Q43.2 (B), R67.2
unnamed: Q43.1 (C), R71.1, R72.1
unnamed: Q43.3 (E), Q44.1 (C)
unnamed: Q44.2 (B), R68.2
unnamed: Q45.2 (B), R72.2
unnamed: Q45.1 (C), R73.1, R77.1
unnamed: Q46.2 (B), R73.2
unnamed: Q46.1 (C), Q47.1 (C), R78.1, R80.1
unnamed: Q47.2 (B), R74.2
unnamed: Q48.2 (B), R75.2
unnamed: Q48.3 (E), Q49.1 (C)
unnamed: Q49.2 (B), R76.2
unnamed: Q50.2 (B), R80.2
unnamed: Q51.2 (B), R82.2
unnamed: Q51.1 (C), R84.1, R86.1, R87.1
unnamed: Q51.3 (E), Q52.1 (C)
unnamed: Q52.2 (B), R83.2
unnamed: Q53.2 (B), R85.2
unnamed: Q53.1 (C), R91.1, R95.1
unnamed: Q53.3 (E), Q54.1 (C)
unnamed: Q54.2 (B), R86.2
unnamed: Q55.2 (B), R87.2
unnamed: Q55.1 (C), R92.1, R96.1
unnamed: Q55.3 (E), Q56.1 (C)
unnamed: Q56.2 (B), R88.2
unnamed: Q57.2 (B), R89.2
unnamed: Q57.1 (C), R93.1, R94.1
unnamed: Q57.3 (E), Q58.1 (C)
unnamed: Q58.2 (B), R90.2
unnamed: Q59.2 (B), R94.2
unnamed: Q59.1 (C), R97.1, R113.1
unnamed: Q60.2 (B), R95.2
unnamed: Q60.1 (C), R98.1, R99.1, R102.1, R107.1
unnamed: Q60.3 (E), Q61.1 (C)
unnamed: Q61.2 (B), R96.2
unnamed: Q62.2 (B), R99.2
unnamed: Q62.1 (C), R101.1, R103.1, R104.1
unnamed: Q62.3 (E), Q63.1 (C)
unnamed: Q63.2 (B), R100.2
unnamed: Q64.2 (B), R102.2
unnamed: Q64.1 (C), R108.1, R114.1
unnamed: Q64.3 (E), Q65.1 (C)
unnamed: Q65.2 (B), R103.2
unnamed: Q66.2 (B), R104.2
unnamed: Q66.1 (C), R109.1, R115.1
unnamed: Q66.3 (E), Q67.1 (C)
unnamed: Q67.2 (B), R105.2
unnamed: Q68.2 (B), R106.2
unnamed: Q68.1 (C), R110.1, R111.1
unnamed: Q68.3 (E), Q69.1 (C)
unnamed: Q69.2 (B), R107.2
unnamed: Q70.2 (B), R111.2
unnamed: Q70.1 (C), R112.1, R116.1
unnamed: Q71.2 (B), R112.2
unnamed: Q71.1 (C), Q72.1 (C), R117.1, R119.1
unnamed: Q72.2 (B), R113.2
unnamed: Q73.2 (B), R114.2
unnamed: Q73.3 (E), Q74.1 (C)
unnamed: Q74.2 (B), R115.2
unnamed: Q75.2 (B), R119.2
unnamed: Q76.2 (B), R121.2
unnamed: Q76.1 (C), R123.1, R125.1, R126.1
unnamed: Q76.3 (E), Q77.1 (C)
unnamed: Q77.2 (B), R122.2
unnamed: Q78.2 (B), R124.2
unnamed: Q78.1 (C), R130.1, R134.1
unnamed: Q78.3 (E), Q79.1 (C)
unnamed: Q79.2 (B), R125.2
unnamed: Q80.2 (B), R126.2
unnamed: Q80.1 (C), R131.1, R135.1
unnamed: Q80.3 (E), Q81.1 (C)
unnamed: Q81.2 (B), R127.2
unnamed: Q82.2 (B), R128.2
unnamed: Q82.1 (C), R132.1, R133.1
unnamed: Q82.3 (E), Q83.1 (C)
unnamed: Q83.2 (B), R129.2
unnamed: Q84.2 (B), R133.2
unnamed: Q84.1 (C), R136.1, R152.1
unnamed: Q85.2 (B), R134.2
unnamed: Q85.1 (C), R137.1, R138.1, R141.1, R146.1
unnamed: Q85.3 (E), Q86.1 (C)
unnamed: Q86.2 (B), R135.2
unnamed: Q87.2 (B), R138.2
unnamed: Q87.1 (C), R140.1, R142.1, R143.1
unnamed: Q87.3 (E), Q88.1 (C)
unnamed: Q88.2 (B), R139.2
unnamed: Q89.2 (B), R141.2
unnamed: Q89.1 (C), R147.1, R153.1
unnamed: Q89.3 (E), Q90.1 (C)
unnamed: Q90.2 (B), R142.2
unnamed: Q91.2 (B), R143.2
unnamed: Q91.1 (C), R148.1, R154.1
unnamed: Q91.3 (E), Q92.1 (C)
unnamed: Q92.2 (B), R144.2
unnamed: Q93.2 (B), R145.2
unnamed: Q93.1 (C), R149.1, R150.1
unnamed: Q93.3 (E), Q94.1 (C)
unnamed: Q94.2 (B), R146.2
unnamed: Q95.2 (B), R150.2
unnamed: Q95.1 (C), R151.1, R155.1
unnamed: Q96.2 (B), R151.2
unnamed: Q96.1 (C), Q97.1 (C), R156.1, R158.1
unnamed: Q97.2 (B), R152.2
unnamed: Q98.2 (B), R153.2
unnamed: Q98.3 (E), Q99.1 (C)
unnamed: Q99.2 (B), R154.2
unnamed: Q100.2 (B), R158.2
unnamed: F1.2, SW9.2 (B)
unnamed: R165.2, U7.13 (A_OUT)
unnamed: R166.2, U7.12 (B_OUT)
unnamed: R167.2, U7.11 (C_OUT)
unnamed: R168.2, U7.10 (D_OUT)
unnamed: R169.2, U7.9 (E_OUT)
unnamed: R170.2, U7.15 (F_OUT)
unnamed: R171.2, U7.14 (G_OUT)
unnamed: R172.2, U8.13 (A_OUT)
unnamed: R173.2, U8.12 (B_OUT)
unnamed: R174.2, U8.11 (C_OUT)
unnamed: R175.2, U8.10 (D_OUT)
unnamed: R176.2, U8.9 (E_OUT)
unnamed: R177.2, U8.15 (F_OUT)
unnamed: R178.2, U8.14 (G_OUT)
unnamed: R165.1, U9.7 (A)
unnamed: R166.1, U9.6 (B)
unnamed: R167.1, U9.4 (C)
unnamed: R168.1, U9.2 (D)
unnamed: R169.1, U9.1 (E)
unnamed: R170.1, U9.9 (F)
unnamed: R171.1, U9.10 (G)
unnamed: R172.1, U10.7 (A)
unnamed: R173.1, U10.6 (B)
unnamed: R174.1, U10.4 (C)
unnamed: R175.1, U10.2 (D)
unnamed: R176.1, U10.1 (E)
unnamed: R177.1, U10.9 (F)
unnamed: R178.1, U10.10 (G)

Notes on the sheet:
4-bit Summator
Power
5-bit to BCD
Binary OUTPUT
Ones
Switches
Tens

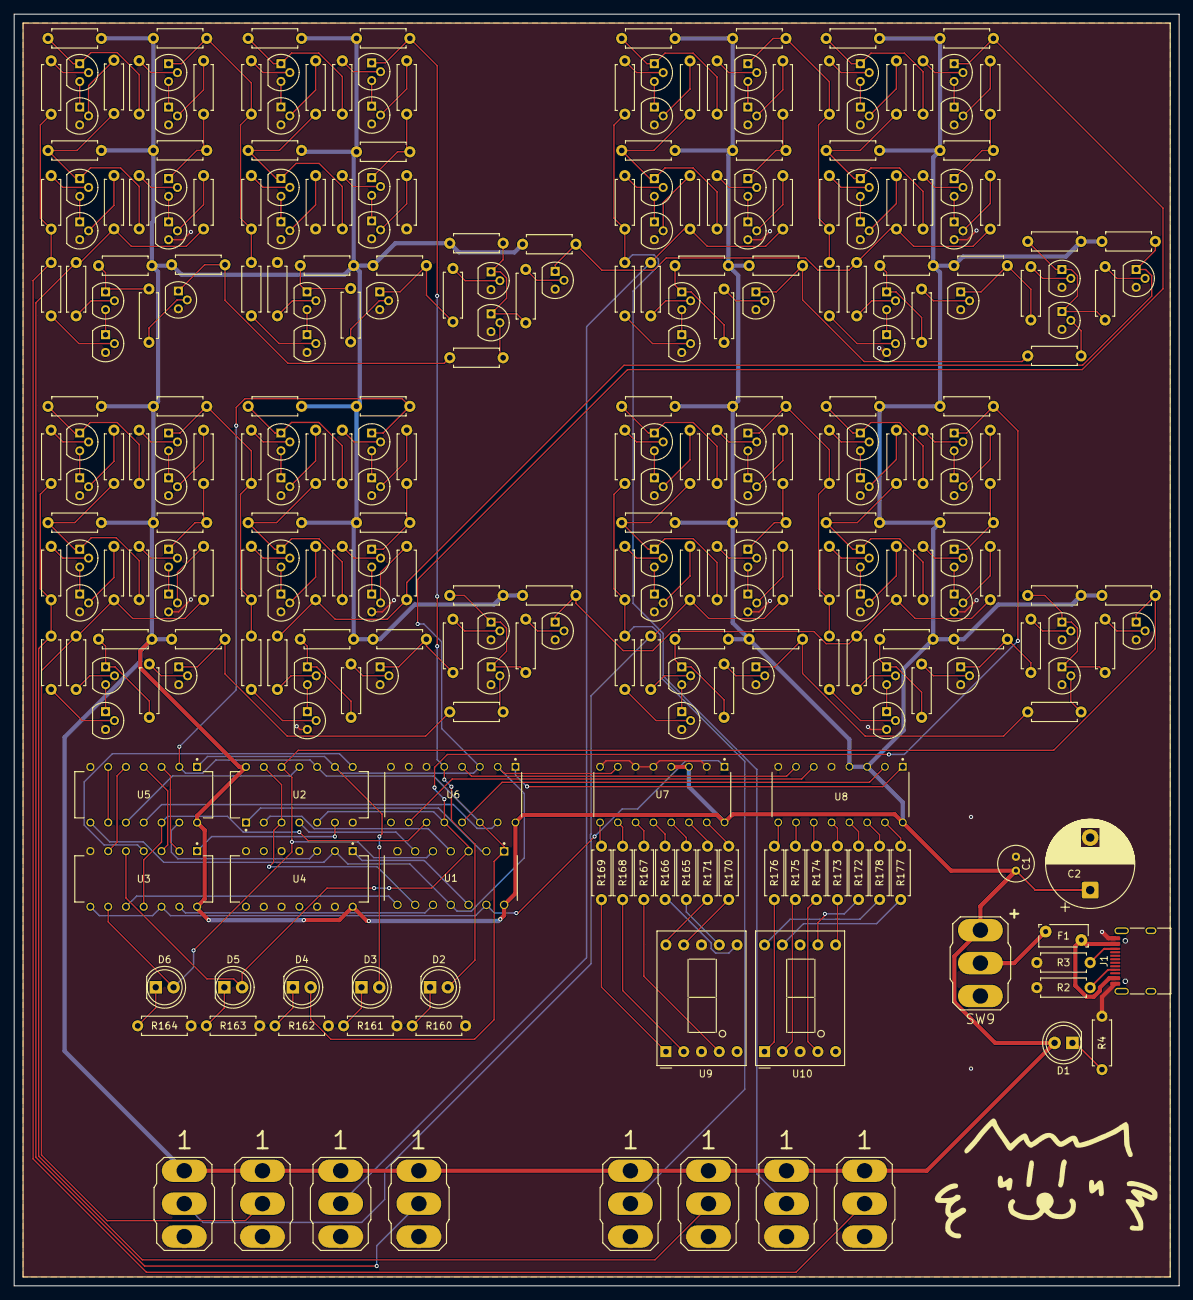
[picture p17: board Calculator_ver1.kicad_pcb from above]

Board: 2 copper layers, 166.4 x 181.6 mm, 308 parts (0 on the bottom side), 267 nets.

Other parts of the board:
g: LOGO; logocat

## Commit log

2026-09-09 Enhance README with simulation details
    Added detailed documentation for the circuit simulation, including components used, input/output descriptions, and verification process.
2026-09-09 Add README for circuit simulation documentation
    Added detailed README for circuit simulation including overview, components, input/output specifications, and verification process.
